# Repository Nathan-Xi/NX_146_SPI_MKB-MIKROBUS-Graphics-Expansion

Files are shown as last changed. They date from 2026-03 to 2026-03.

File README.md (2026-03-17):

# NX_146_SPI_MKB MIKROBUS™ Graphics Expansion Board
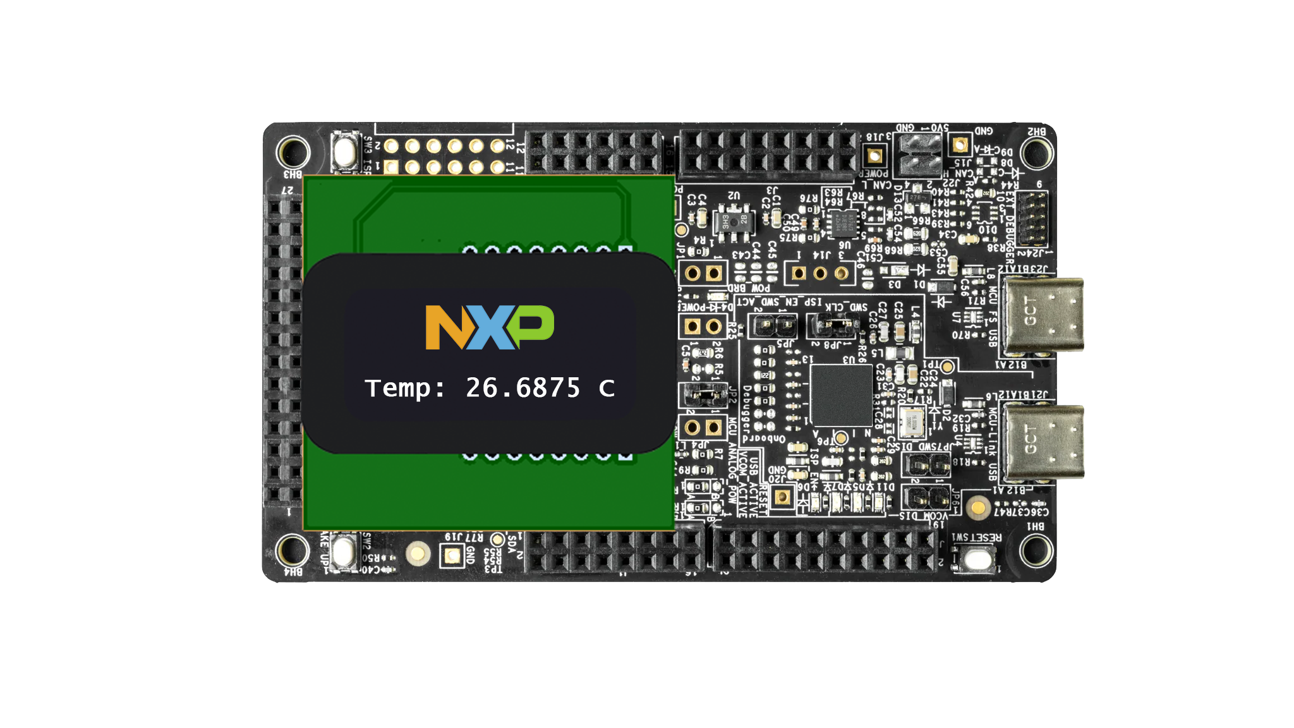
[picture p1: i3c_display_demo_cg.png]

**Thank you for noticing this project.**:blush:

This is a graphics expansion board designed for all MIKROBUS™ supported development boards! (but you can still use it for other general-purpose applications as it's just a 4-SPI screen adapter board)

In **this** example SDK, I used an NXP FRDM-MCXA156 for demonstration.

## Parameters

**Display product name:** 鱼鹰光电DP146BT001-V12  
**Resolution:** 70×160  
**Display area size:** 1.46 inch  
**Touch:** capacitive  
**Screen IC:** NV3022  
**Touch panel IC:** CST08C  
**Interface:** 4-SPI (for display) & I2C (for touch panel)  
**ESD protection:** no  
**On-board external flash:** no  
**On-board cache:** no  

## Demos

### Demo 1: whiteboard

This demo turns the display into a whiteboard on which you can test the touch panel.✏️

The demo project (for MCUXpresso) was fully packed into a .zip called "whiteboard_demo.zip" (but of course you have to build and debug it by yourself)

### Demo 2: I3C temperature sensor data visualization

This demo is specific to the FRDM-MCXA156 development board.🔒

It uses the on-board MEMS temperature sensor (p3t1755) and reads it using the I3C bus.

## How to use the demos

The two demos are essential as they include the driver which the contributer had written (as this display acquires no existing driver).

If you want to port the driver to a new platform, please refer to Demo 1 as it included all you need for your custom project.

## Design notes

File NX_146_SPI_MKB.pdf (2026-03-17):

NX_146_SPI_MKB V0.1 Graphics Expansion

Nathan XI | nathanxi@shu.edu.cn

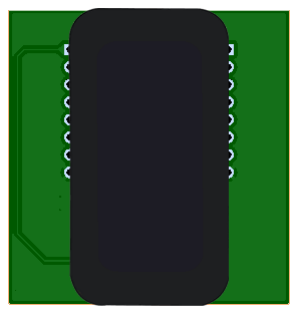
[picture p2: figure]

Size: 4.06×4.25cm

### Interface: 4SPI

Touch: I2C

### IC: NV3022

### Touch IC: CST08C

This expansion board is a third⁻party

composition of the MIKROBUS™ ecosystem,

which expands the possibility of driving an

LCD⁻TFT display with touch panel using

the MIKROBUS™ interface on a bunch of

development boards. The prebuilt, open

source driver enables you to integrate

this board into your project within

minutes.

Designers: Nathan XI, Yao Mei

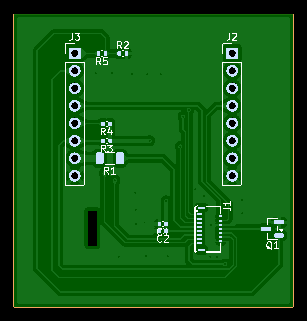
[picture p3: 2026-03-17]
board_top.png

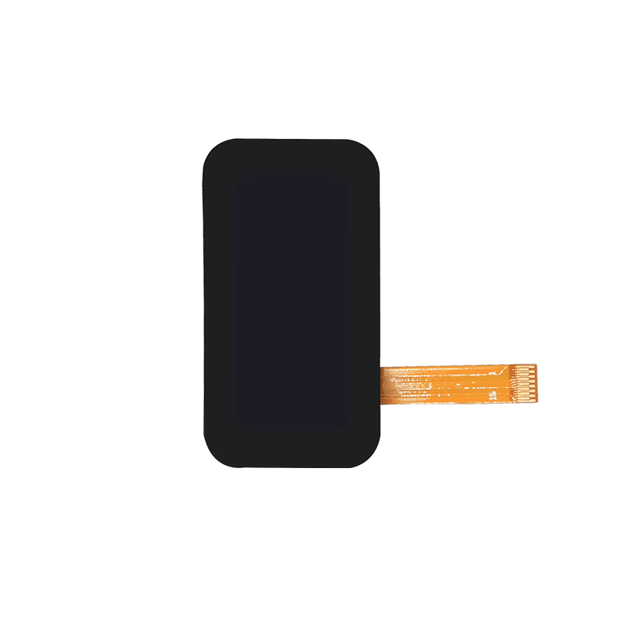
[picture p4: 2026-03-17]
screen_dim.png

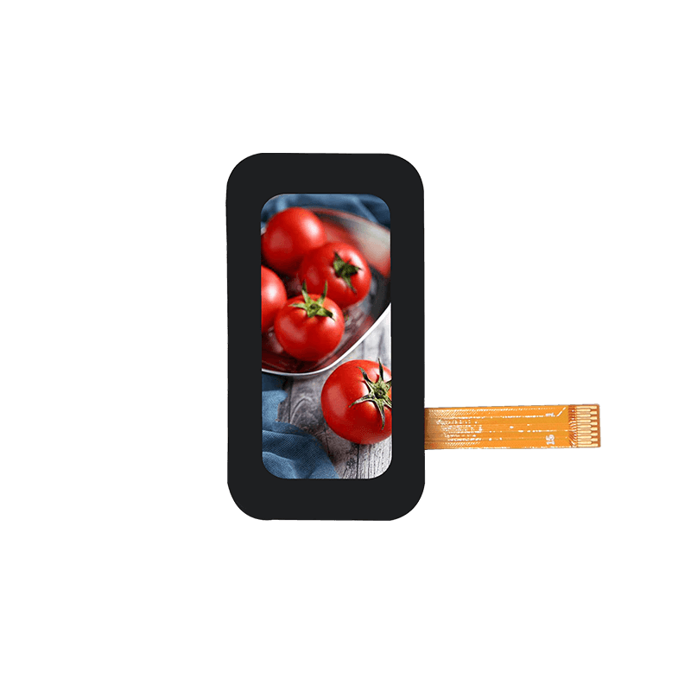
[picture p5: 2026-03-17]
screen_light.png

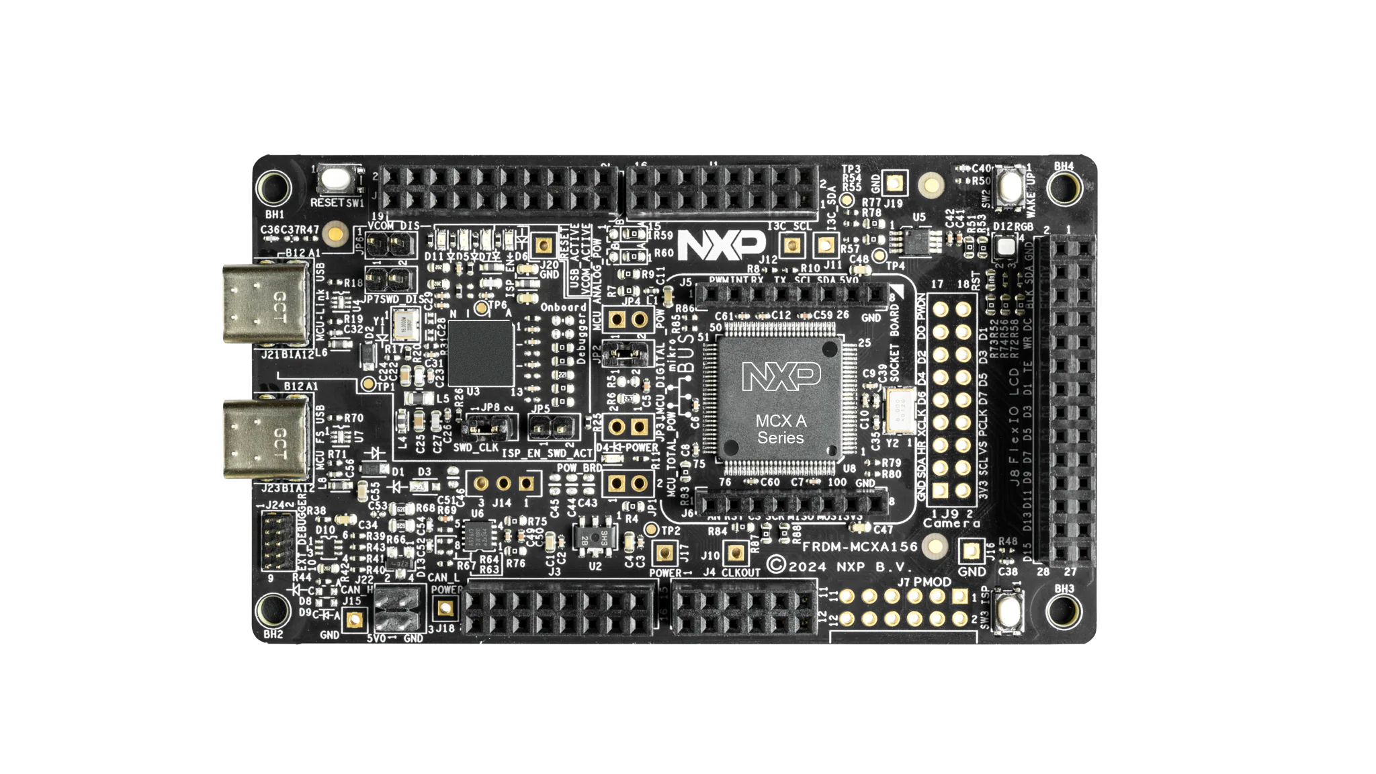
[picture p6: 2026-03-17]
FRDM-MCXA156-TOP.webp

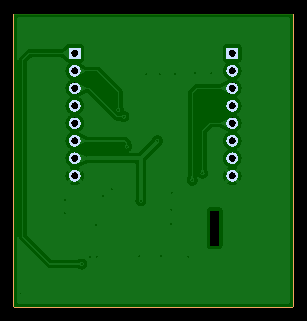
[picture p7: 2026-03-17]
board_bottom.png

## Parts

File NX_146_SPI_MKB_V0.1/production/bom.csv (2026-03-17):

Designator | Footprint | Quantity | Value | LCSC Part #
C1 | 0402 | 1 | 1uF
C2 | 0402 | 1 | 0.1uF
J1 | FPC-SMD_15P-P0.30_HDGC_.3K-HX-15PWB | 1 | LCD_INTERFACE
J2 | PinHeader_1x08_P2.54mm_Vertical | 1 | MIKROBUS_1_SOCKET
J3 | PinHeader_1x08_P2.54mm_Vertical | 1 | MIKROBUS_2_SOCKET
Q1 | SOT-23 | 1 | AO3400A
R1 | 1206 | 1 | 33R
R2 | 0402 | 1 | 4.7k
R3, R4 | 0402 | 2 | 5.1k
R5 | 0402 | 1 | 100R

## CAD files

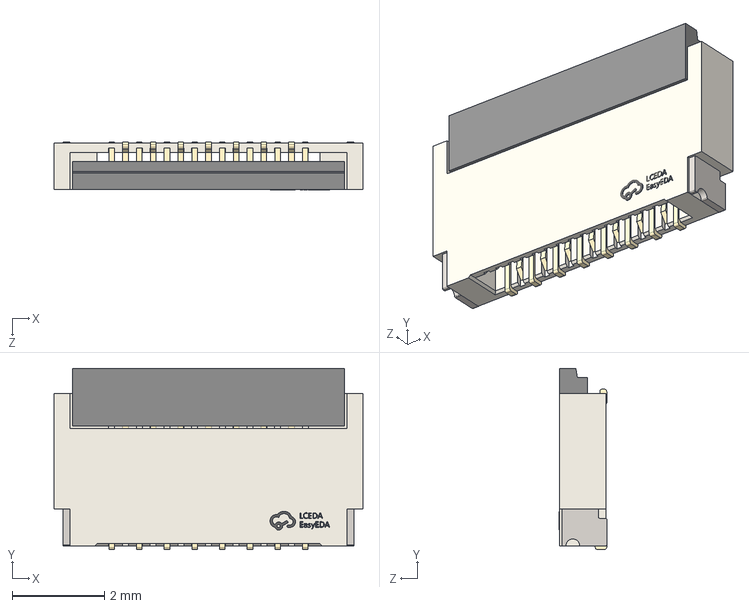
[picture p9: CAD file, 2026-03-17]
0.3K-HX-15PWB.3dmodels/FPC-SMD_15P-P0.30_HDGC_.3K-HX-15PWB.step
6.70 x 3.93 x 1.03 mm

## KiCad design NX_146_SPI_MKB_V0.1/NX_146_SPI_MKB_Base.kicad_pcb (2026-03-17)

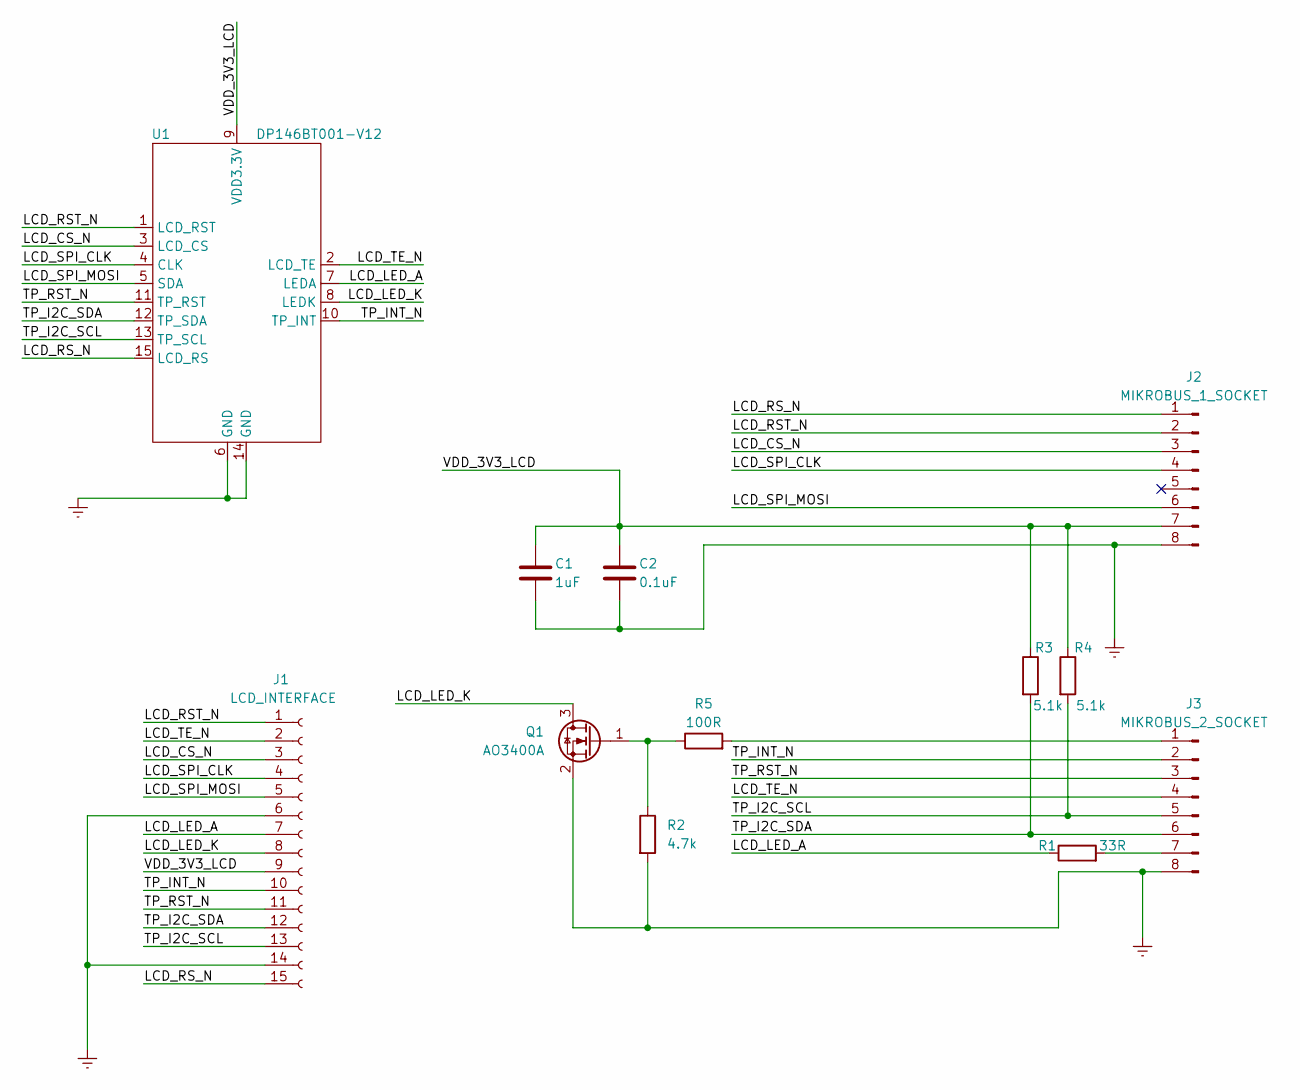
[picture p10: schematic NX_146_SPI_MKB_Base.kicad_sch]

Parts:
C1: 1uF; C_0402_1005Metric
C2: 0.1uF; C_0402_1005Metric
J1: LCD_INTERFACE; FPC-SMD_15P-P0.30_HDGC_.3K-HX-15PWB
J2: MIKROBUS_1_SOCKET; PinHeader_1x08_P2.54mm_Vertical
J3: MIKROBUS_2_SOCKET; PinHeader_1x08_P2.54mm_Vertical
Q1: AO3400A; SOT-23
R1: 33R; R_1206_3216Metric
R2: 4.7k; R_0402_1005Metric
R3, R4: 5.1k; R_0402_1005Metric
R5: 100R; R_0402_1005Metric
U1: DP146BT001-V12

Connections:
/LCD_CS_N: J1.3, J2.3, U1.3 (LCD_CS)
/LCD_LED_A: J1.7, R1.1, U1.7 (LEDA)
/LCD_LED_K: J1.8, Q1.3 (D), U1.8 (LEDK)
/LCD_RST_N: J1.1, J2.2, U1.1 (LCD_RST)
/LCD_RS_N: J1.15, J2.1, U1.15 (LCD_RS)
/LCD_SPI_CLK: J1.4, J2.4, U1.4 (CLK)
/LCD_SPI_MOSI: J1.5, J2.6, U1.5 (SDA)
/LCD_TE_N: J1.2, J3.4, U1.2 (LCD_TE)
/TP_I2C_SCL: J1.13, J3.5, R4.2, U1.13 (TP_SCL)
/TP_I2C_SDA: J1.12, J3.6, R3.2, U1.12 (TP_SDA)
/TP_INT_N: J1.10, J3.2, U1.10 (TP_INT)
/TP_RST_N: J1.11, J3.3, U1.11 (TP_RST)
/VDD_3V3_LCD: C1.1, C2.1, J1.9, J2.7, R3.1, R4.1, U1.9 (VDD3.3V)
Earth: C1.2, C2.2, J1.6, J1.14, J2.8, J3.8, Q1.2 (S), R2.2, U1.6 (GND), U1.14 (GND)
unnamed: J3.1, R5.2
unnamed: J3.7, R1.2
unnamed: Q1.1 (G), R2.1, R5.1

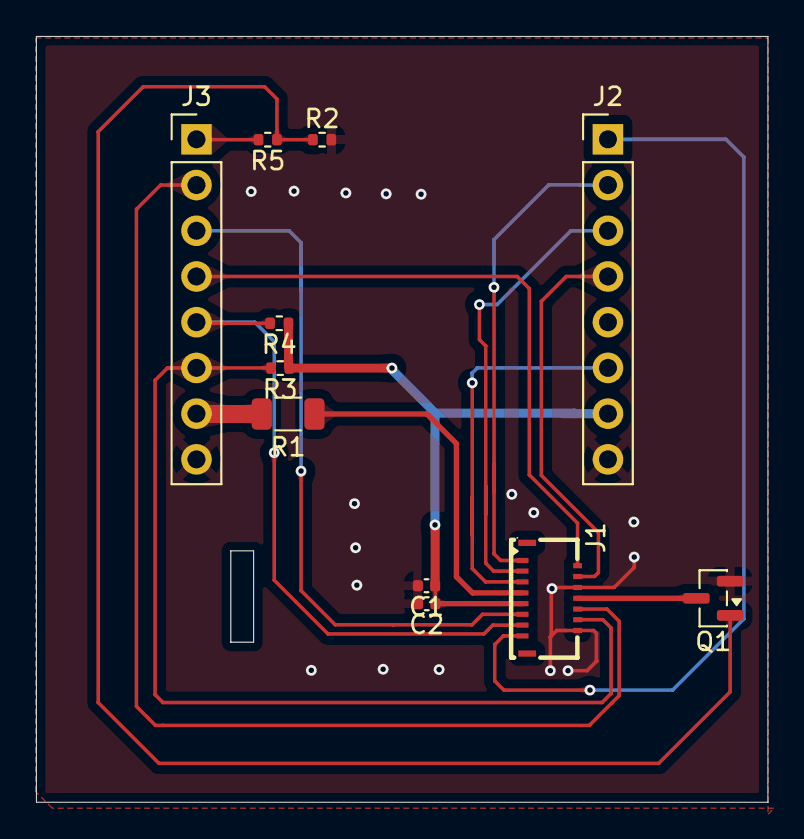
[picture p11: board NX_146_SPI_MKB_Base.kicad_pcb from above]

Board: 4 copper layers, 40.6 x 42.5 mm, 11 parts (0 on the bottom side), 17 nets.
